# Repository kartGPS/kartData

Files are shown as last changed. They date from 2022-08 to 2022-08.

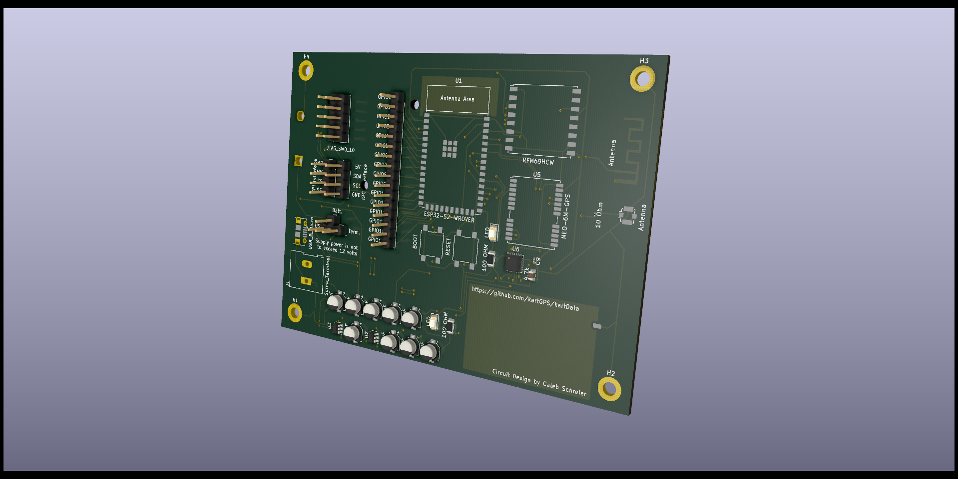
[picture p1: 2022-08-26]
Photos/PCB Render.png

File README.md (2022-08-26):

# kartData
Electrical Specifications and Software for the GPS puck intended for use in LETU Go-kart races. Designed initially by Caleb Schreier, Summer 2022

Hardware design is done. Software is in development.

This device supports WIFI, BlueTooth, and LoRa Radio Communications and is designed to be installed in Go-Karts for LeTourneau University's Official Go-Kart Race. 
The purpose of this device is to allow constant communication between the Kart and a stationary computer, potentially even many computers, as software is 
currently in development to allow the chip's microprocessor, an ESP32 WROVER, to connect to an external webserver and, through a websocket, convey process data 
to the server. The device is equipped with an accelerometer, GPS module, and in the case of insufficient WIFI, is equipped with a LoRa module, a low-power, radio-communications device with potential of data transmission at 10+ kilometers.

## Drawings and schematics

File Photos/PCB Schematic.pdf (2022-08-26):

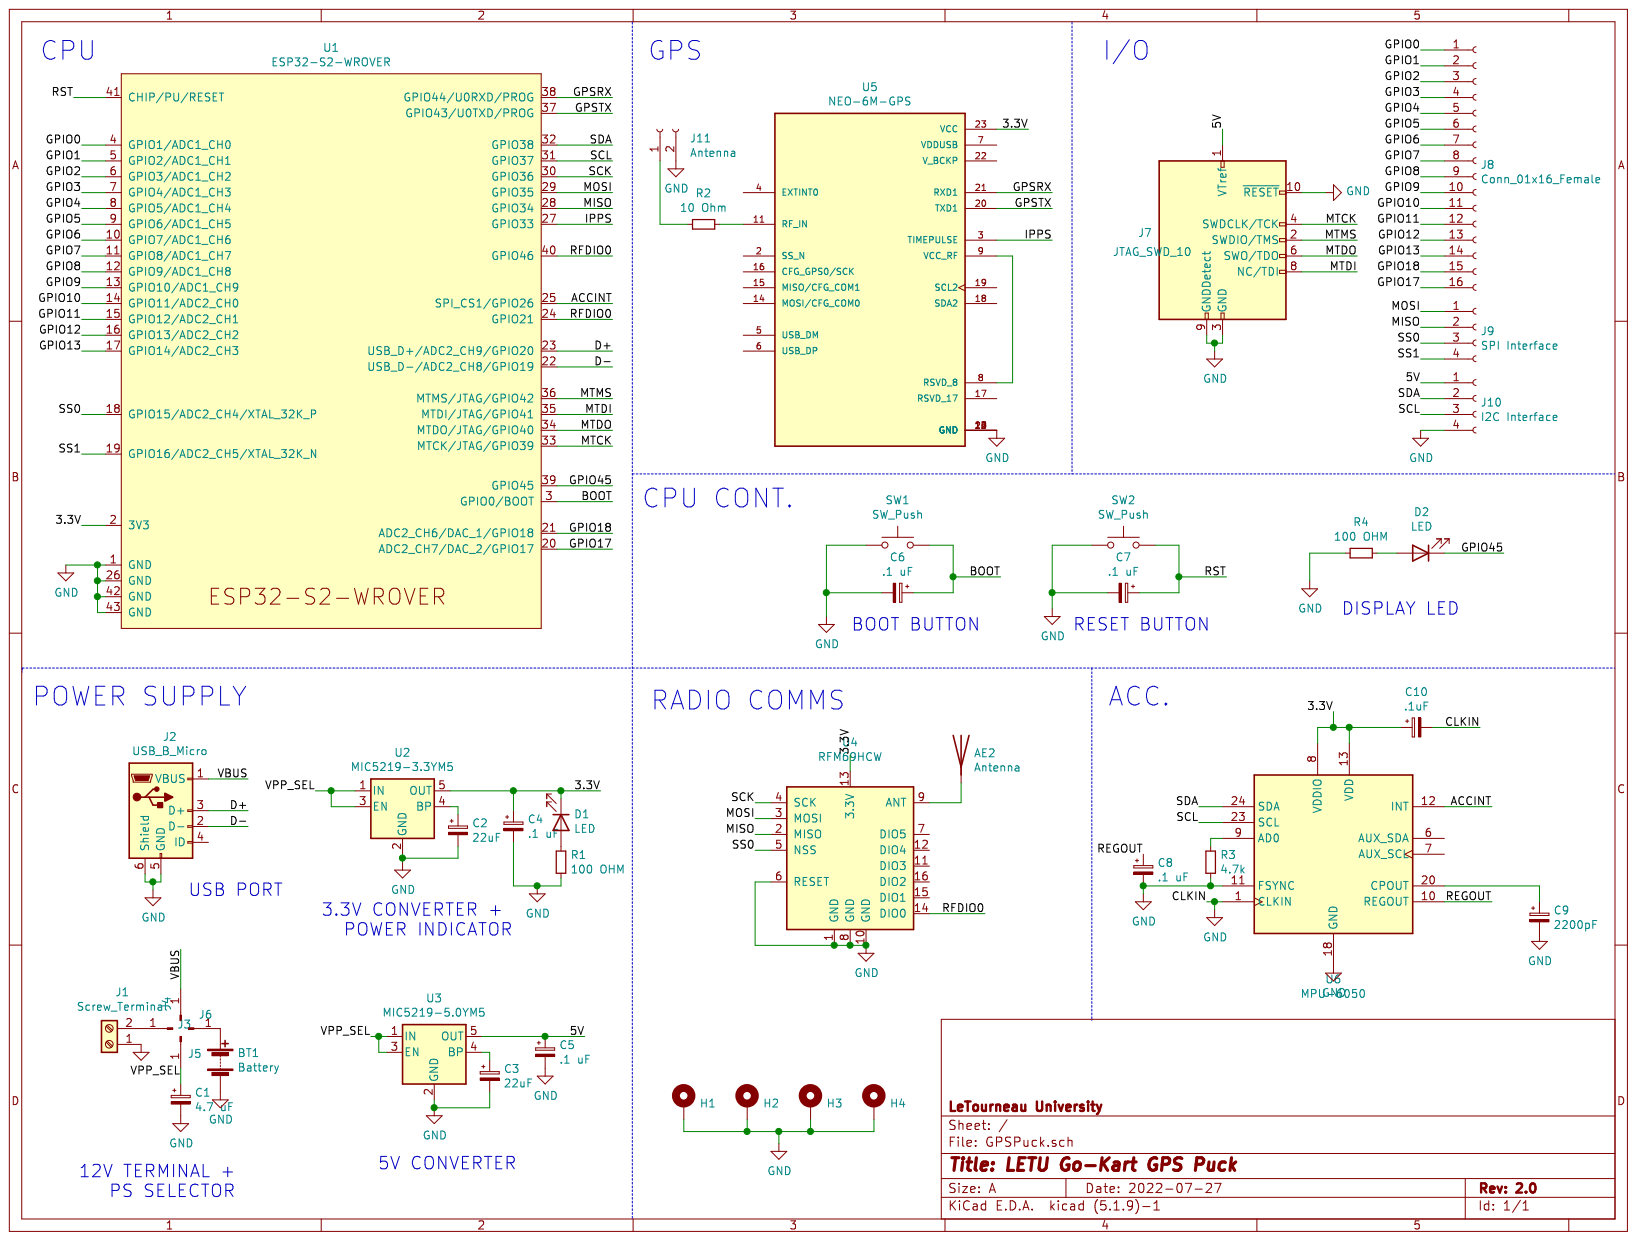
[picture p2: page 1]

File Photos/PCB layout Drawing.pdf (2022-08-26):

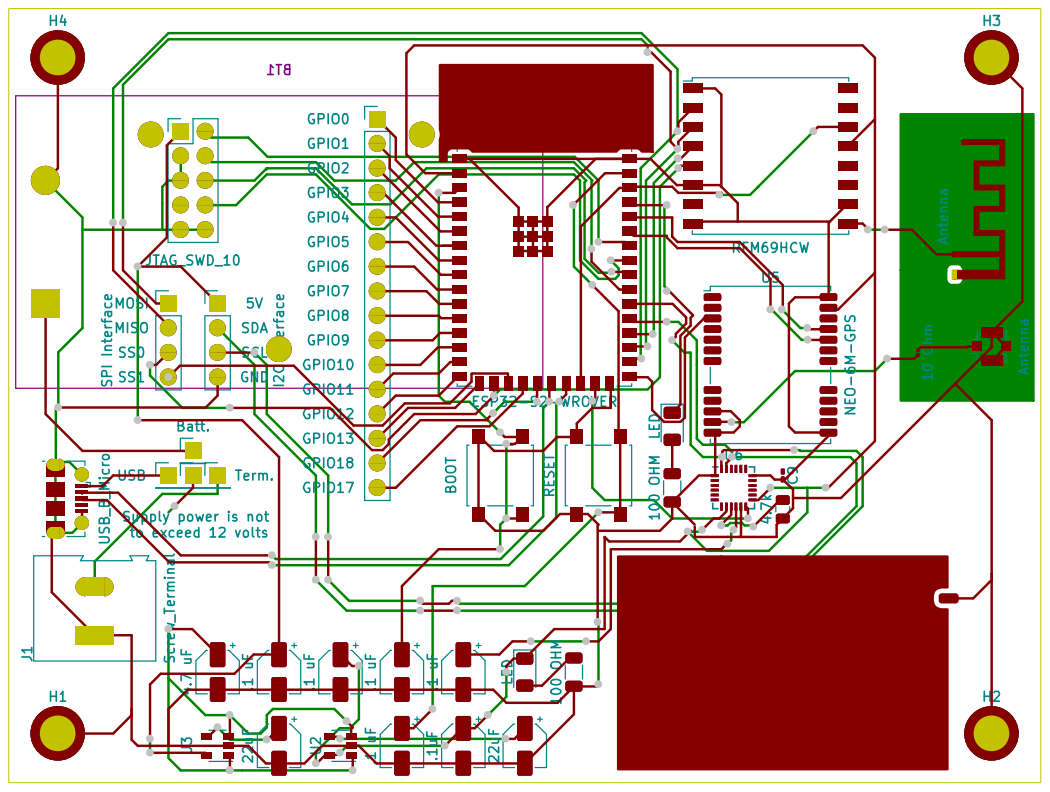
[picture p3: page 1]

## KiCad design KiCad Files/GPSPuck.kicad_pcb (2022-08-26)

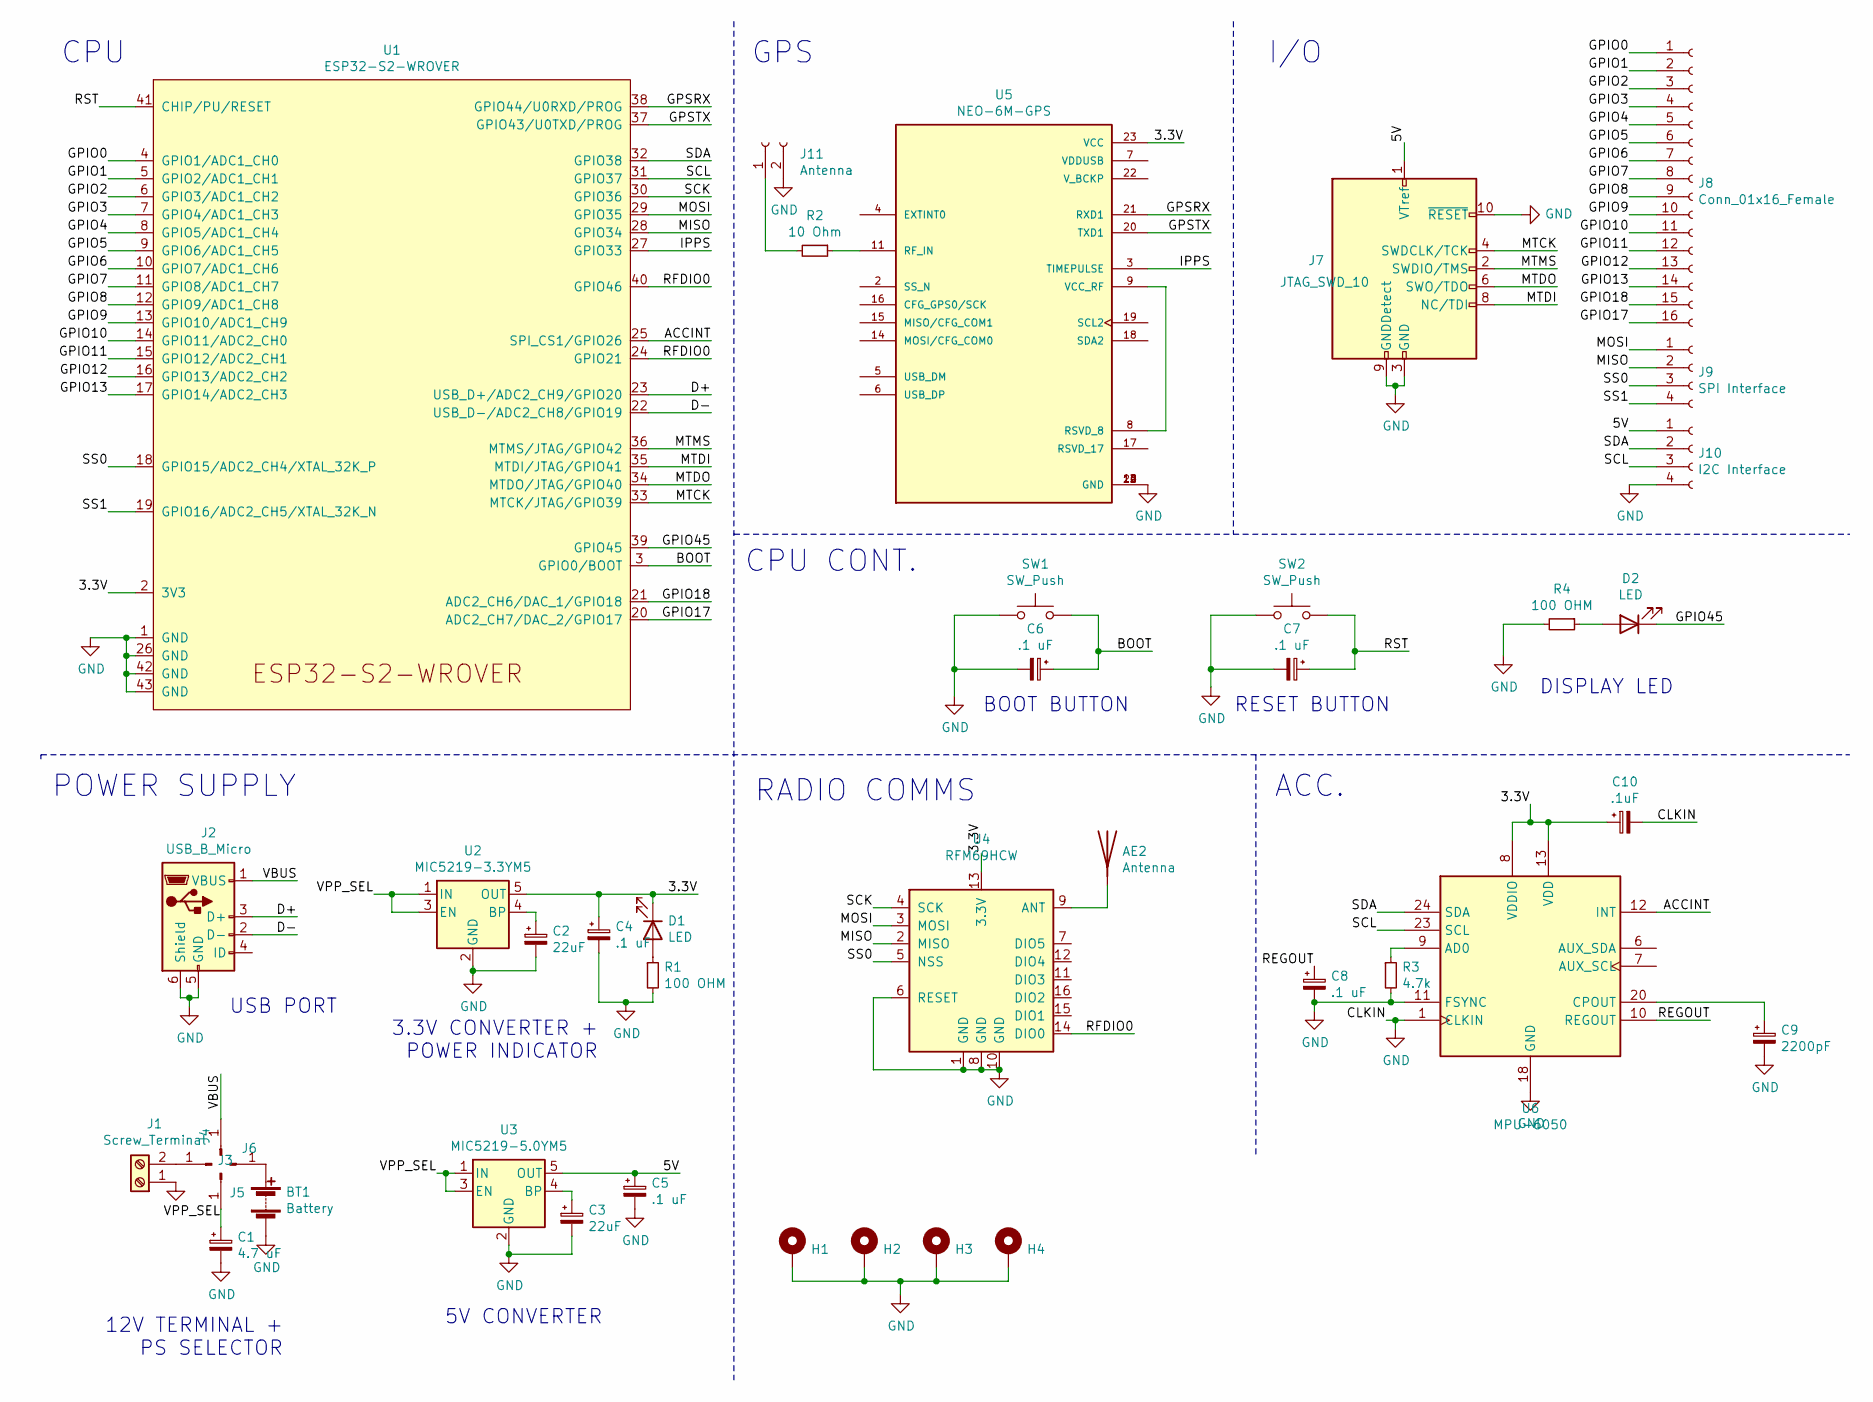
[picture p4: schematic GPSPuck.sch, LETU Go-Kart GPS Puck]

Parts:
AE2: Antenna; Texas_SWRA117D_2.4GHz_Left
BT1: Battery; BatteryHolder_Eagle_12BH611-GR
C1: 4.7 uF; CP_Elec_4x3
C2, C3: 22uF; CP_Elec_4x3
C4, C5, C6, C7, C8: .1 uF; CP_Elec_4x3
C9: 2200pF; C_0201_0603Metric_Pad0.64x0.40mm_HandSolder
C10: .1uF; CP_Elec_4x3
D1, D2: LED; LED_1206_3216Metric
H1, H2, H3, H4: MountingHole_Pad; MountingHole_3.2mm_M3_DIN965_Pad_TopBottom
J1: Screw_Terminal; TerminalBlock_Altech_AK300-2_P5.00mm
J2: USB_B_Micro; USB_Micro-B_Molex-105017-0001
J3: Conn_01x01; PinHeader_1x01_P2.54mm_Vertical
J4, J5, J6: Conn_01x01_Male; PinHeader_1x01_P2.54mm_Vertical
J7: JTAG_SWD_10; PinHeader_2x05_P2.54mm_Vertical
J8: Conn_01x16_Female; PinHeader_1x16_P2.54mm_Vertical
J9: SPI Interface; PinHeader_1x04_P2.54mm_Vertical
J10: I2C Interface; PinHeader_1x04_P2.54mm_Vertical
J11: Antenna; U.FL_Molex_MCRF_73412-0110_Vertical
R1, R4: 100 OHM; R_1206_3216Metric
R2: 10 Ohm; R_01005_0402Metric
R3: 4.7k; C_0805_2012Metric
SW1, SW2: SW_Push; SW_SPST_B3S-1000
U1: ESP32-S2-WROVER
U2: MIC5219-3.3YM5; SOT-23-5
U3: MIC5219-5.0YM5; SOT-23-5
U4: RFM69HCW; HOPERF_RFM9XW_SMD
U5: NEO-6M-GPS; ublox_NEO; PARTREV R15
U6: MPU-6050; InvenSense_QFN-24_4x4mm_P0.5mm

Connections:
/3.3V: C4.1, C10.1, D1.1 (K), U1.2 (3V3), U2.5 (OUT), U4.13 (3.3V), U5.23 (VCC), U6.8 (VDDIO), U6.13 (VDD)
/5V: C5.1, J7.1 (VTref), J10.1, U3.5 (OUT)
/ACCINT: U1.25 (SPI_CS1/GPIO26), U6.12 (INT)
/BOOT: C6.1, SW1.2, U1.3 (GPIO0/BOOT)
/D+: J2.3 (D+), U1.23 (USB_D+/ADC2_CH9/GPIO20)
/D-: J2.2 (D-), U1.22 (USB_D-/ADC2_CH8/GPIO19)
/GPIO0: J8.1, U1.4 (GPIO1/ADC1_CH0)
/GPIO1: J8.2, U1.5 (GPIO2/ADC1_CH1)
/GPIO2: J8.3, U1.6 (GPIO3/ADC1_CH2)
/GPIO3: J8.4, U1.7 (GPIO4/ADC1_CH3)
/GPIO4: J8.5, U1.8 (GPIO5/ADC1_CH4)
/GPIO5: J8.6, U1.9 (GPIO6/ADC1_CH5)
/GPIO6: J8.7, U1.10 (GPIO7/ADC1_CH6)
/GPIO7: J8.8, U1.11 (GPIO8/ADC1_CH7)
/GPIO8: J8.9, U1.12 (GPIO9/ADC1_CH8)
/GPIO9: J8.10, U1.13 (GPIO10/ADC1_CH9)
/GPIO10: J8.11, U1.14 (GPIO11/ADC2_CH0)
/GPIO11: J8.12, U1.15 (GPIO12/ADC2_CH1)
/GPIO12: J8.13, U1.16 (GPIO13/ADC2_CH2)
/GPIO13: J8.14, U1.17 (GPIO14/ADC2_CH3)
/GPIO17: J8.16, U1.20 (ADC2_CH7/DAC_2/GPIO17)
/GPIO18: J8.15, U1.21 (ADC2_CH6/DAC_1/GPIO18)
/GPIO45: D2.1 (K), U1.39 (GPIO45)
/GPSRX: U1.38 (GPIO44/U0RXD/PROG), U5.21 (RXD1)
/GPSTX: U1.37 (GPIO43/U0TXD/PROG), U5.20 (TXD1)
/IPPS: U1.27 (GPIO33), U5.3 (TIMEPULSE)
/MISO: J9.2, U1.28 (GPIO34), U4.2 (MISO)
/MOSI: J9.1, U1.29 (GPIO35), U4.3 (MOSI)
/MTCK: J7.4 (SWDCLK/TCK), U1.33 (MTCK/JTAG/GPIO39)
/MTDI: J7.8 (NC/TDI), U1.35 (MTDI/JTAG/GPIO41)
/MTDO: J7.6 (SWO/TDO), U1.34 (MTDO/JTAG/GPIO40)
/MTMS: J7.2 (SWDIO/TMS), U1.36 (MTMS/JTAG/GPIO42)
/REGOUT: C8.1, U6.10 (REGOUT)
/RFDIO0: U1.24 (GPIO21), U1.40 (GPIO46), U4.14 (DIO0)
/RST: C7.1, SW2.2, U1.41 (CHIP/PU/RESET)
/SCK: U1.30 (GPIO36), U4.4 (SCK)
/SCL: J10.3, U1.31 (GPIO37), U6.23 (SCL)
/SDA: J10.2, U1.32 (GPIO38), U6.24 (SDA)
/SS0: J9.3, U1.18 (GPIO15/ADC2_CH4/XTAL_32K_P), U4.5 (NSS)
/SS1: J9.4, U1.19 (GPIO16/ADC2_CH5/XTAL_32K_N)
/VBUS: J2.1 (VBUS), J4.1
/VPP_SEL: C1.1, J5.1, U2.1 (IN), U2.3 (EN), U3.1 (IN), U3.3 (EN)
GND: BT1.2 (-), C1.2, C2.2, C3.2, C4.2, C5.2, C6.2, C7.2, C8.2, C9.2, C10.2, H1.1, H2.1, H3.1, H4.1, J1.1, J2.5 (GND), J2.6 (Shield), J7.3 (GND), J7.5 (GND), J7.9 (GNDDetect), J7.10 (~RESET~), J10.4, J11.2, R1.2, R3.2, R4.2, SW1.1, SW2.1, U1.1 (GND), U1.26 (GND), U1.42 (GND), U1.43 (GND), U2.2 (GND), U3.2 (GND), U4.1 (GND), U4.6 (RESET), U4.8 (GND), U4.10 (GND), U5.10 (GND), U5.12 (GND), U5.13 (GND), U5.24 (GND), U6.1 (CLKIN), U6.11 (FSYNC), U6.18 (GND)
unnamed: AE2.1, U4.9 (ANT)
unnamed: BT1.1 (+), J6.1
unnamed: C2.1, U2.4 (BP)
unnamed: C3.1, U3.4 (BP)
unnamed: C9.1, U6.20 (CPOUT)
unnamed: D1.2 (A), R1.1
unnamed: D2.2 (A), R4.1
unnamed: J1.2, J3.1
unnamed: J11.1, R2.2
unnamed: R2.1, U5.11 (RF_IN)
unnamed: R3.1, U6.9 (AD0)
unnamed: U5.8 (RSVD_8), U5.9 (VCC_RF)

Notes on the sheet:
I/O
GPS
CPU
POWER SUPPLY
RADIO COMMS
ACC.
CPU CONT.
BOOT BUTTON
RESET BUTTON
DISPLAY LED
USB PORT
3.3V CONVERTER + POWER INDICATOR
5V CONVERTER
12V TERMINAL + PS SELECTOR

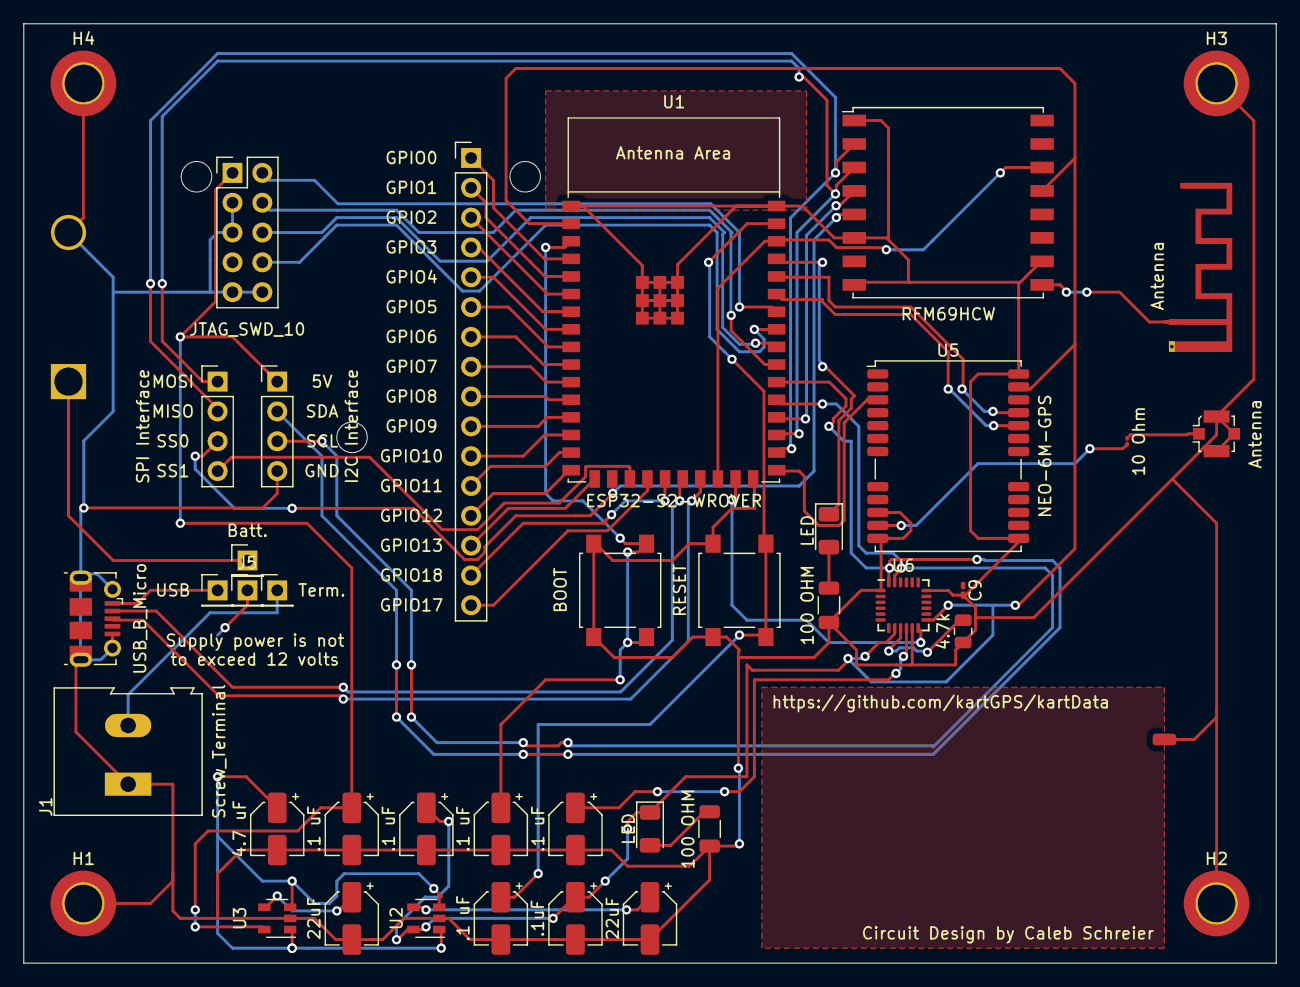
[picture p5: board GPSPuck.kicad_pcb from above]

Board: 2 copper layers, 106.7 x 80.0 mm, 41 parts (1 on the bottom side), 55 nets.

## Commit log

2022-07-25 Initial KiCAD Project (unfinished layout, unrouted)
    [FA2022GoKart.kicad_pcb, FA2022GoKart.sch, GPSPuck.kicad_pcb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]
2022-07-26 Finished Layout and Routing
    [GPSPuck-B_Cu.gbr, GPSPuck-B_Mask.gbr, GPSPuck-B_Paste.gbr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]
2022-07-28 Corrected antenna footprint, grounded hole masks, and added ground planes
    [GPSPuck-B_Cu.gbr, GPSPuck-B_Mask.gbr, GPSPuck-B_Paste.gbr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]
2022-08-26 Added Footprint Centroid file
    [GPSPuck-B_Cu.gbr, GPSPuck-B_Fab.gbr, GPSPuck-B_Mask.gbr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]
2022-08-26 Fixed mislabeled C10
    [GPSPuck.kicad_pcb, GPSPuck.sch]
2022-08-26 First Ed. -- JTAG Connector Differs from KiCad Specs
    [GPSPuckBOM.csv]
